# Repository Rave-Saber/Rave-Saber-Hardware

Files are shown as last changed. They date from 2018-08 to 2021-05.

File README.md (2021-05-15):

# RaveSaber - AVR Hardware

This repository contains the circuit diagram, PCB schematics, prototype board
layout, parts list, & setup guide for the RaveSaber electronics.

There is no blade or hilt at the moment, but you can swing the LEDs
around using the PCB or prototype board & a piece of wood.

## Electronics Design

The Rave Saber board includes voltage regulation, utility headers, input
buttons, and an Atmel ATmega168a microchip.

### Connectors

The various RaveSaber connectors

`J1` is where power enters the board from the battery. We use JST connectors
for our battery wiring. The battery power is fed through the power sub-circuit
to get a regulated voltage of 5V.

`J2` is where the Dotstar strips connect to the board. The data & clock signals
come from the microchip while the power connections come from the power
circuit.

`J3` & `J4` are optional connectors that ease programming & development. `J3`
is a FTDI Serial connection that can be used to preview/sample different colors
with our [color testing firmware][color-test]. `J4` is an ISP connector that
allows you to re-program the microchip without having to pull it out of it's
socket.

### Power

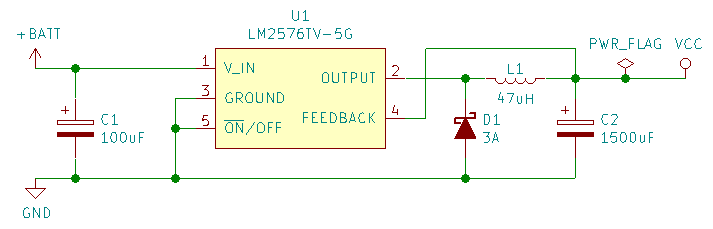
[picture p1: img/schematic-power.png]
The RaveSaber voltage regulation circuit


The power circuit uses a LM2576TV-5G switching voltage regulator to step down
the battery voltage to 5V. It can pump out a maximum of 3 Amps, which is used
to power the microcontroller & the LEDs.

The circuit design is derived from the voltage regulator's datasheet. `C1` &
`C2` should be low-ESR capacitors rated for at least 16V(with a minimum ESR of
50 milliOhms for `C2`). `C2` can be anywhere from 1000 to 2000 uF. `L1` must be
an inductor rated for at least 3 amps, going slightly over that is encouraged.
`D1` should be rated for 20V.

### Microcontroller

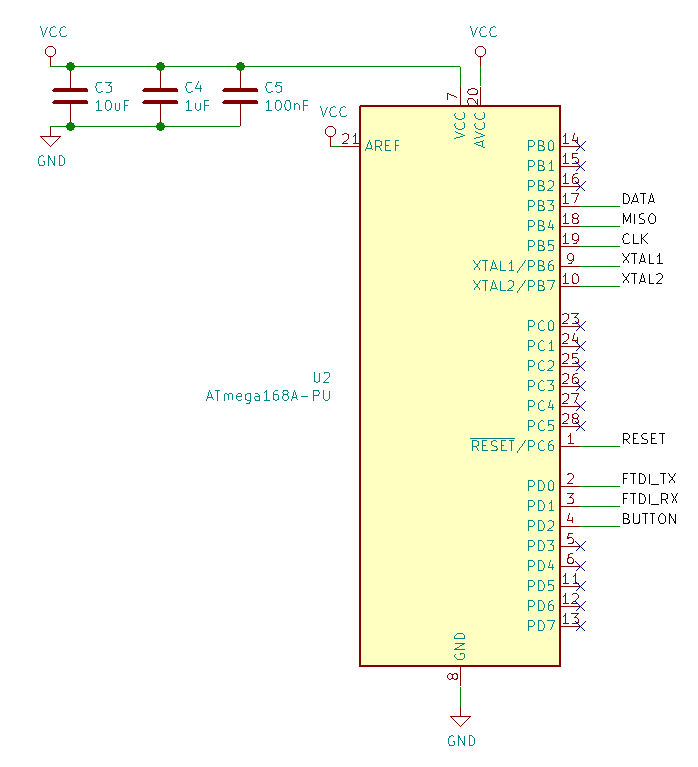
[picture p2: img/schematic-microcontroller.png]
The RaveSaber microcontroller connections


The microcontroller circuit is mostly just connections to the other circuits.

Bypass capacitors are used on the connection to the power circuit. `C3` & `C4`
are optional but `C5`, the 100nF capacitor, should always be included. The
analog reference & power pins are connected to the power supply even though
they are not used - this is recommended in the ATmega datasheet.

### Crystal Oscillator

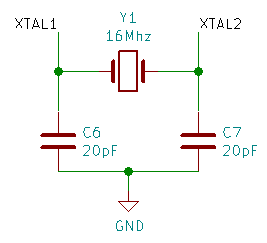
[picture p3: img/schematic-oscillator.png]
The RaveSaber oscillator circuit


The oscillator circuit is pretty fluid. You can use a different frequency
crystal(with a maximum of 20Mhz), or leave out the entire circuit and use the
ATmega's 8Mhz internal oscillator instead. If you do modify the circuit, make
sure your microcontroller's fuses are correctly programmed for your desired
clock source and change the definition of the `F_CPU` macro in the firmware's
`Makefile` to your new frequency.

### Button

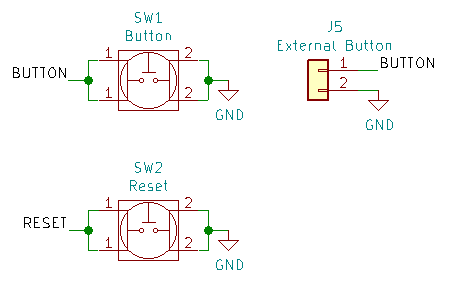
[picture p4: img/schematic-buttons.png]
The RaveSaber button circuits


The main button is `SW1`. It is used to ignite/extinguish the saber & cycle
through the programmed patterns. We've included both a tactile switch for
development and an external connection so you can put your board in a hilt.

The reset button, `SW2`, is optional but ocassionally useful for testing &
development.

## Required Materials

### Equipment

You'll want to have the following equipment/supplies:

* 22AWG Solid Hookup Wire
* AVR Programmer(like the [USBtinyISP][usbtinyisp])
* Wire Strippers
* Flush Cutters
* Soldering Iron & Solder
* PCB Holder(optional)
* Anti-static Bracelet or ESD-safe Tweezers(optional)

If you're only testing this out on a breadboard you can get away with just:

* Breadboard
* Wire & Strippers
* AVR Programmer
* 5V Power Supply

### Components

For the breadboard, you just need a Dotstar strip, an ATmega168a
microcontroller & a tactile button.

For the prototyping board, you will need the following:

| Part | Description | Link |
|---|---|---|
| | 22x27 through-hole prototyping board | [Amazon][protoboard] |
| BAT | 7.4v Li-Ion battery | [TCSS][battery] |
| LED | DotStar Strip, 144/m | [Mouser][led-strip] |
| J1 | 2-pin JST connector | [TCSS][jst-power-connector] |
| J2 | 4-pin, 2.54mm pitch male header | [Amazon][headers] |
| J3 | 6-pin, 2.54mm pitch male header | [Amazon][headers] |
| J4 | 2x3-pin, 2.54mm pitch male header | [Amazon][headers] |
| C1 | 100uF low-ESR electrolytic capacitor | [Mouser][100-cap] |
| C2 | 1000-2000uF low-ESR electrolytic capacitor | [Mouser][1200-cap] |
| C3 | 10uF capacitor | [Amazon(assorted)][elec-cap-kit] |
| C4 | 1uF capacitor | [Amazon(assorted)][elec-cap-kit] |
| C5 | 100nF capacitor | [Amazon(assorted)][cer-cap-kit] |
| C6, C7 | 20pF capacitor | [Mouser][20-cap] |
| D1 | 3A, 20V Schottky Diode | [Mouser][diode] |
| L1 | 47uH, 3A Fixed Inductor | [Mouser][inductor] |
| Y1 | 16Mhz Crystal | [Mouser][crystal] |
| SW1, SW2 | 6mm SPST OFF-(ON) tactile switch | [Mouser][switch] |
| U1 | LM2576TV-5G - 5V, 3A switching voltage regulator | [Mouser][vreg] |
| U2 | 28-pin DIP IC socket | [Amazon][dip-socket] |
| U2 | Atmel ATmega168A-PU - AVR microcontroller | [Mouser][atmega] |

[protoboard]: https://amzn.to/2L2IWVJ
[battery]: http://www.thecustomsabershop.com/74v-Li-ion-2600mAh-18650-Battery-Pack-P699.aspx
[led-strip]: https://www.mouser.com/ProductDetail/485-2242
[jst-power-connector]: https://www.thecustomsabershop.com/JST-Female-connector-24AWG-RedBlack-P964.aspx
[headers]: https://amzn.to/2Mx6HtK
[100-cap]: https://www.mouser.com/ProductDetail/710-870135675003
[1200-cap]: https://www.mouser.com/ProductDetail/667-EEU-FC1A122S
[elec-cap-kit]: https://amzn.to/2wb0Ekk
[cer-cap-kit]: https://amzn.to/2PiyX1K
[20-cap]: https://www.mouser.com/ProductDetail/594-S200K25SL0N63L6R
[diode]: https://www.mouser.com/ProductDetail/863-1N5820G
[inductor]: https://www.mouser.com/ProductDetail/673-PE-53112NL
[crystal]: https://www.mouser.com/ProductDetail/520-HCA1600-20X
[switch]: https://www.mouser.com/ProductDetail/506-FSM4JH
[vreg]: https://www.mouser.com/ProductDetail/863-LM2576TV-5G
[dip-socket]: https://amzn.to/2Mo4dOU
[atmega]: https://www.mouser.com/ProductDetail/556-ATMEGA168A-PU

For the circuit board, you will need SMD components instead:

| Part | Description | Link
|---|---|---|
| | RaveSaber v3.0.0 PCB | [OSHPark][pcb-3.0.0]
| BAT | 7.4v Li-Ion battery | [TCSS][battery] |
| LED | DotStar Strip, 144/m | [Mouser][led-strip] |
| J1 | 2-pin JST connector | [TCSS][jst-power-connector]
| J2 | 4-pin, 2.54mm pitch male header | [Mouser][pcb-4-pin]
| J3 | 6-pin, 2.54mm pitch male header | [Mouser][pcb-6-pin]
| J4 | 2x3-pin, 2.54mm pitch male header | [Mouser][pcb-2-3-pin]
| J5 | 2-pin JST connector | [TCSS][jst-switch-connector]
| C1 | 100uF low-ESR electrolytic capacitor | [Mouser][pcb-100-cap] |
| C2 | 1500uF low-ESR electrolytic capacitor | [Mouser][pcb-1500-cap] |
| C3 | 10uF capacitor | [Mouser][pcb-10-cap] |
| C4 | 1uF capacitor | [Mouser][pcb-1-cap] |
| C5 | 100nF capacitor | [Mouser][pcb-100n-cap] |
| C6, C7 | 20pF capacitor | [Mouser][pcb-20-cap] |
| D1 | 3A, 20V Schottky Diode | [Mouser][pcb-diode] |
| L1 | 47uH, 3A Fixed Inductor | [Mouser][pcb-inductor] |
| Y1 | 20Mhz Crystal | [Mouser][pcb-crystal] |
| SW1, SW2 | 4.5mm SPST OFF-(ON) tactile switch | [Mouser][pcb-switch] |
| U1 | LM2576TV-5G - 5V, 3A switching voltage regulator | [Mouser][vreg] |
| U2 | 28-pin DIP IC Socket | [Mouser][pcb-dip-socket] |
| U2 | Atmel ATmega168A-PU - AVR microcontroller | [Mouser][atmega] |

NOTE: The 4- & 6-pin headers link to a 20-pin header. We simply break this into
the sizes necessary with some pliers.

NOTE: The DIP socket for `U2` is machine-holed. You may prefer a leaf-spring
socket instead.

[pcb-3.0.0]: https://oshpark.com/shared_projects/t8VlH9g8
[pcb-4-pin]: https://www.mouser.com/ProductDetail/Samtec/TSM-120-01-S-SV-P
[pcb-6-pin]: https://www.mouser.com/ProductDetail/Samtec/TSM-120-01-S-SV-P
[pcb-2-3-pin]: https://www.mouser.com/ProductDetail/855-M20-8750342
[jst-switch-connector]: https://www.thecustomsabershop.com/JST-Female-connector-24AWG-BlueWhite-P958.aspx
[pcb-100-cap]: https://www.mouser.com/ProductDetail/661-EMZJ350A101MHA0G
[pcb-1500-cap]: https://www.mouser.com/ProductDetail/598-AFK158M16H32T-F
[pcb-10-cap]: https://www.mouser.com/ProductDetail/810-C1608X5R1E106M
[pcb-1-cap]: https://www.mouser.com/ProductDetail/80-C0603X105J4R
[pcb-100n-cap]: https://www.mouser.com/ProductDetail/581-0603X7R104JT1AT
[pcb-20-cap]: https://www.mouser.com/ProductDetail/603-CC603GRNPO9BN200
[pcb-diode]: https://www.mouser.com/ProductDetail/621-B320A-F
[pcb-inductor]: https://www.mouser.com/ProductDetail/710-744373965470
[pcb-crystal]: https://www.mouser.com/ProductDetail/559-FOXSDLF200-20
[pcb-switch]: https://www.mouser.com/ProductDetail/612-TL3305AF260QG
[pcb-dip-socket]: https://www.mouser.com/ProductDetail/575-1104732841105000

## Setup

### Breadboard

A breadboard can be used for simple testing of colors/patterns as well as
flashing the microchip with new firmware. You could use a smaller breadboard
for the saber instead of a prototyping board, but it's not nearly as durable.
Be wary of drawing too much current through your breadboard - you might melt
it! Initial attempts used batteries and voltage regulation with the breadboard,
but these instructions will assume you are running everything off a 5V bench
power supply.

1. Place the ATmega168a chip in the center of the breadboard.
1. Connect the switch to ground and pin 4(PD2/INT0) of the microchip.
1. Connect pin 19(SCK) to the Dotstar strip's clock pin & pin 17(MOSI) to the
   strip's data pin.
1. Connect your power supply's 5V & ground leads to the microchip & Dotstar
   strip.

You should now be able to connect the GND, SCK, MOSI, MISO, & RESET pins of
your programmer and flash your chip with the [RaveSaber Firmware][firmware].
Leave the VCC pin on your programmer unconnected since power is coming from
your bench supply.

### Prototyping Board

A prototyping board is the recommended way to setup v2.0.0 of the RaveSaber
hardware.

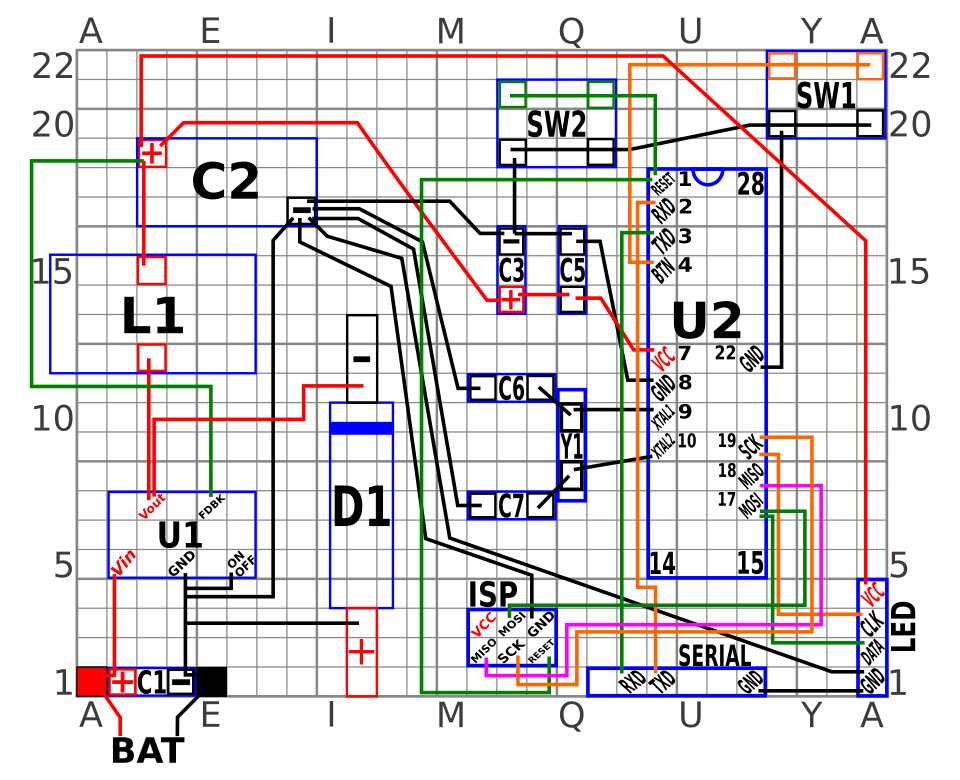
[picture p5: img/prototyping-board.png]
The Prototyping Board Layout of the RaveSaber v2.0.0


The prototyping board is assembled by placing components and bridging pads with
component leads, solder bridges, & wire. We've ommited `C4`, the 1uF decoupling
capacitor but feel free to add it in.

First we place the components and make what connections we can with the
component leads:

1. Start by placing the capacitors on the board and bending the leads so they
   stay on the board when you flip it over. You can also tack them into place
   with a small amount of solder.
1. Place the switches and voltage regulator. These should fit tight enough that
   they don't fall out when you flip the board over. If they do, tack them into
   place with some solder on the pins.
1. Place the DIP socket for `U2` and tack it into place by soldering some of
   the unused pins.
1. Connect `C1` and `U1` by bending the leads of `C1` and soldering them together.
1. Bridge `GND` & `ON/OFF` of `U1` together. This keeps the regulator always
   running.
1. Place and solder `L1`. Bend & solder the positive lead of `C2` to connect
   the two.
1. Since the leads of `D1` are too thick for the board's holes, bend them down
   the board and solder each one over multiple pads.
1. Connect and solder the negative leads of `C2`, `C3`, `C5`, & `SW2`. Do the
   same with the positive leads of `C3` & `C5`.
1. Use spare lead cuttings to bridge all the ground pins of `SW1` & `SW2`
   together. Bridge the top pins of each switch together as well, keeping the
   tops of `SW1` & `SW2` unconnected.
1. Place & solder `Y1`. Use the right leads of `C6` & `C7` to connect & solder
   them to the crystal and then to the proper DIP-socket pins.
1. Place and solder the `J2`, `J3`, & `J4` headers. Use just enough solder to
   get them to hold into place - it'll make their wire connections easier to
   solder.
1. Bridge the ground pins of the serial & LED headers together. Leave space for
   the ground wire between `C2` and the LED header.

Everything should now be on the board & the remaining connections can be made
with your 22-gauge wire. We did this in the following order:

1. `U1` to `L1`, `D1`, & `C2`.
1. `C3` positive lead to `C2`.
1. `C5` to VCC & GND of `U2`.
1. `U2` second GND(pin 22) to `SW1`.
1. `RESET` from `U2` to `SW2`.
1. `BTN` from `U2` to `SW1`.
1. `TXD` from `U2` to `RXD` of the serial header, followed by `RXD` to `TXD`.
1. `RESET` from `U2` to the ISP header.
1. `C2` to VCC & GND of the LED header.
1. `GND` from `C2` to `C6`, `C7`, & the ISP header.
1. `MOSI` & `SCK` from `U2` to the LED header.
1. `MOSI`, `MISO`, `SCK` from `U2` to the LED header.
1. Connect two wires to `C1` and terminate them with the JST connector.

Everything should be connected, your circuit should resemble the schematics, &
your prototyping board should resemble the above layout.

Place the ATmega168a into the DIP socket at `U2` & connect your Programmer's
ISP cable and the battery. Flash the [RaveSaber Firmware][firmware] &
disconnect the programmer & battery.

### PCB Assembly

You should be decent at soldering SMD components before attempting this.

We recommend soldering `C3` through `C7` first, followed by `U2`, `SW1`, `Y1`,
`SW2`, `J2` through `J4`, `D1`, `C1`, `L1`, `C2`, & finally `U2`. Use female
JST cables for `J1` & `J5`. Scrub with isopropyl alcohol to clean off any flux.

You can now insert & flash the microchip, plug in the battery, connect the
lights, and long-press `SW1` to extend the blade.

### Saber Blade / Hilt

The saber blade & hilt construction is very simple - we haven't put together a
blade or hilt yet so we just attach our LEDs & protoboard to a piece of wood.
We used a long 1x2 that we cut down after assembly. It's heavy, but you can
actually swing it around.

1. Lay your DotStar strip at the end of your board & secure it with 4-5
   zipties. Start at the far end, keeping the strip flat as you work towards
   the center of your wood.
1. Place the prototyping board below the strip, secure it with zipties at both
   ends and one in the center.
1. Flip the board over and place your battery near the board & strip, secure it
   with 3 zipties.
1. Connect the LED strip to the 4-pin header on the board and connect your
   battery to the board's JST connector.

You should now be able to long-press the button to illumunate the blade then
short-press to switch patterns or long-press again to power down the blade.

## TODO

* Auto-generate BOM(using [KiBoM](https://github.com/SchrodingersGat/KiBoM)?)
    * Make sure to add DIP socket, LED strips, etc. to BoM
* Blade construction guide, using TCSS blade parts
* PVC Hilt construction guide
    * Eventually use MHS hilts as well, but that's not open hardware
    * See how much it'd cost to get someone to design an open/free metal hilt
      that machinists could reproduce.
    * Chassis disk design, for use w/ acrylic laser cutting service or online
      machine shop.
* Contact Saber design
    * For doing moves [like this](https://youtu.be/Wgl2wym96k0)
    * Needs to be well balanced - some kind of chassis weighting?
    * Research best balance point for contact sabering
* Recharge port? Recharging blade stub?

### Future Milestones

Rough drafts of future plans

* v3.1.0 - 90deg ISP pins? Source single component for all 1-row pins & have
  assembler break apart. blade build + guide
* v4.0.0 - pcb & chassis that fits in MHS hilts

## References

### Hilts

* [Jay-gon's PVC Hilt Tutorial](http://forums.thecustomsabershop.com/showthread.php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)

### Blades

* [Neopixel Blade Assembly - FX-Sabers](https://www.fx-sabers.com/forum/index.php?PHPSESSID=06jl1sddsstpq4hvnu0c9fat74&topic=51357.0)
* [LED Blade Assembly](https://www.youtube.com/watch?v=Qbl4K-v4G_s)

## License

CERN OHL v1.2

[color-test]: https://github.com/Rave-Saber/AVR-APA102-Color-Tester
[usbtinyisp]: https://learn.adafruit.com/usbtinyisp/overview
[mouser]: https://mouser.com
[firmware]: https://github.com/Rave-Saber/Rave-Saber-Firmware

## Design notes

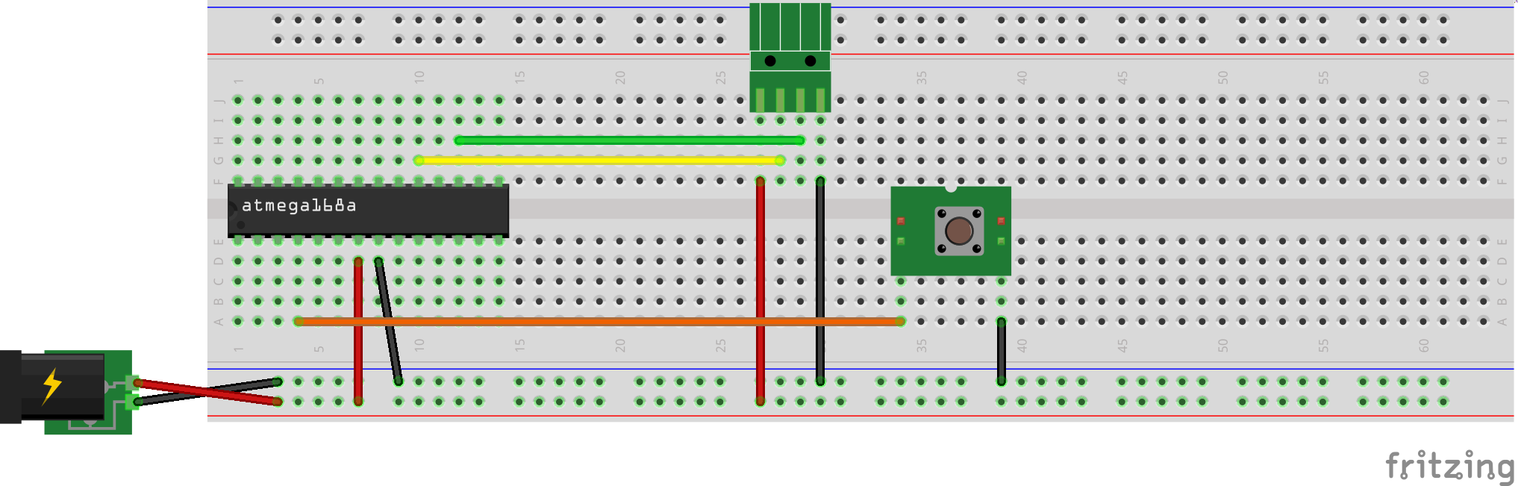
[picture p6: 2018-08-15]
img/breadboard.png

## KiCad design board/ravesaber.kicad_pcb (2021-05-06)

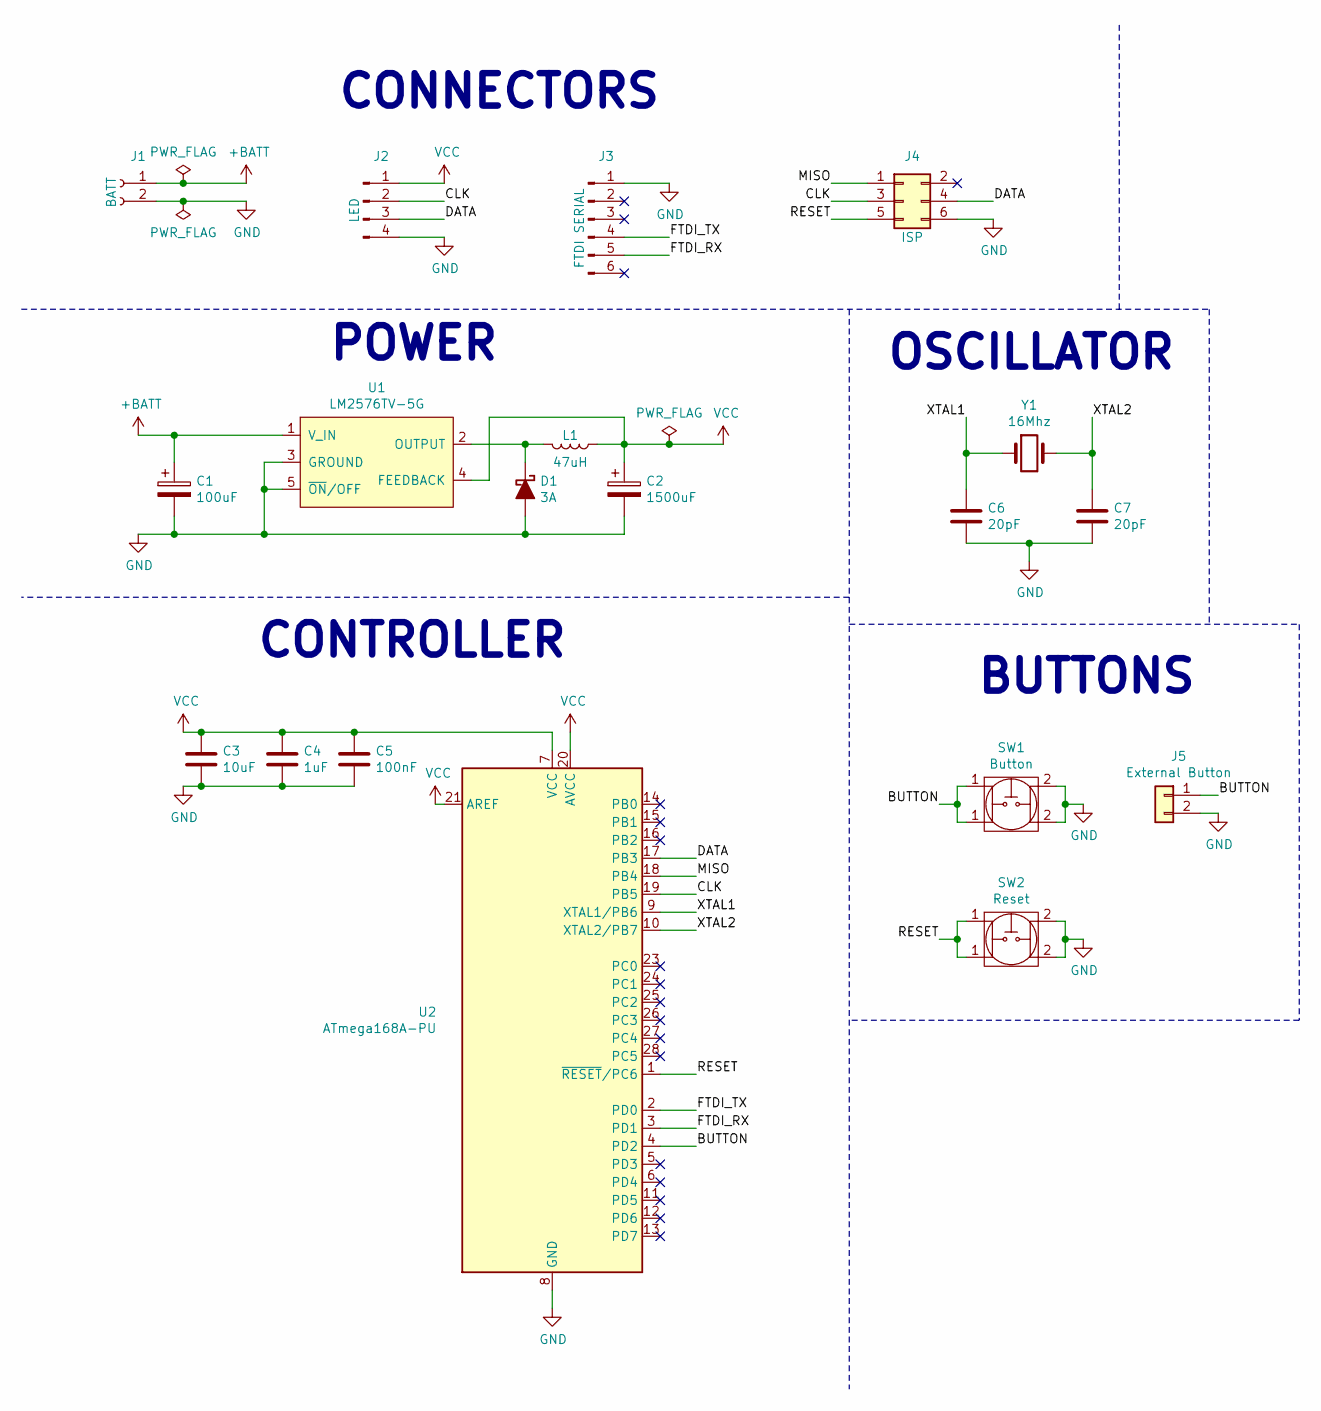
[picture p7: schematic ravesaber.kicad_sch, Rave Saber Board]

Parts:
C1: 100uF; CP_Elec_8x10; Mouser # 661-EMZJ350A101MHA0G
C2: 1500uF; CP_Elec_16x17.5; Mouser # 598-AFK158M16H32T-F
C3: 10uF; C_0603_1608Metric_Pad1.05x0.95mm_HandSolder; Mouser # 810-C1608X5R1E106M
C4: 1uF; C_0603_1608Metric_Pad1.05x0.95mm_HandSolder; Mouser # 80-C0603X105J4R
C5: 100nF; C_0603_1608Metric_Pad1.05x0.95mm_HandSolder; Mouser # 581-0603X7R104JT1AT
C6, C7: 20pF; C_0603_1608Metric_Pad1.05x0.95mm_HandSolder; Mouser # 603-CC603GRNPO9BN200
D1: 3A; D_SMA_Handsoldering; Mouser # 621-B320A-F
J1: BATT; SolderWirePad_1x02_P3.81mm_Drill1.2mm
J2: LED; PinHeader_1x04_P2.54mm_Vertical_SMD_Pin1Left; Mouser # 437-3508010400106101
J3: FTDI SERIAL; PinHeader_1x06_P2.54mm_Vertical_SMD_Pin1Left; Mouser # 855-M20-8770642R
J4: ISP; PinHeader_2x03_P2.54mm_Vertical_SMD; Mouser # 855-M20-8750342
J5: External Button; SolderWirePad_1x02_P3.81mm_Drill1.2mm
L1: 47uH; Wuerth WE-LHMI SMD; Mouser # 710-744373965470
SW1: Button; SW_SPST_TL3305A; Mouser # 612-TL3305AF260QG
SW2: Reset; SW_SPST_TL3305A; Mouser # 612-TL3305AF260QG
U1: LM2576TV-5G; TO-220-5_P3.4x3.7mm_StaggerOdd_Lead3.8mm_Vertical; Mouser # 863-LM2576TV-5G
U2: ATmega168A-PU; DIP-28_W8.89mm_SMDSocket_LongPads; Mouser # 556-ATMEGA168A-PU
Y1: 16Mhz; Crystal_SMD_HC49-SD; Mouser # 559-FOXSD160-20-LF

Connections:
+BATT: C1.1, J1.1, U1.1 (V_IN)
/BUTTON: J5.1, SW1.1, U2.4 (PD2)
/CLK: J2.2, J4.3, U2.19 (PB5)
/DATA: J2.3, J4.4, U2.17 (PB3)
/FTDI_RX: J3.5, U2.3 (PD1)
/FTDI_TX: J3.4, U2.2 (PD0)
/MISO: J4.1, U2.18 (PB4)
/RESET: J4.5, SW2.1, U2.1 (~RESET~/PC6)
/XTAL1: C6.1, U2.9 (XTAL1/PB6), Y1.1
/XTAL2: C7.1, U2.10 (XTAL2/PB7), Y1.2
GND: C1.2, C2.2, C3.2, C4.2, C5.2, C6.2, C7.2, D1.2 (A), J1.2, J2.4, J3.1, J4.6, J5.2, SW1.2, SW2.2, U1.3 (GROUND), U1.5 (~ON~/OFF), U2.8 (GND), U2.22 (GND)
unnamed: D1.1 (K), L1.2, U1.2 (OUTPUT)
VCC: C2.1, C3.1, C4.1, C5.1, J2.1, L1.1, U1.4 (FEEDBACK), U2.7 (VCC), U2.20 (AVCC), U2.21 (AREF)

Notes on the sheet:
CONTROLLER
POWER
CONNECTORS
OSCILLATOR
BUTTONS

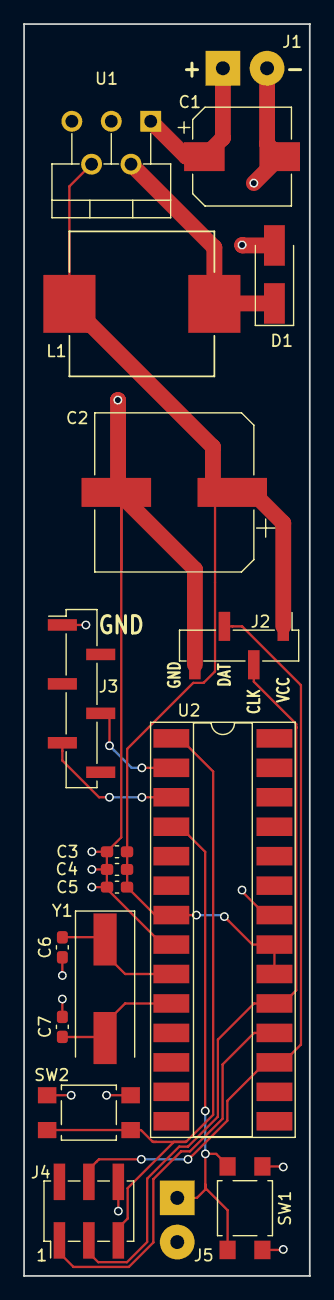
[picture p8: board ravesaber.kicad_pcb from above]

Board: 2 copper layers, 24.6 x 108.0 mm, 20 parts (1 on the bottom side), 13 nets.

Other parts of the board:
svg2mod: G***; AntiFA_Logo

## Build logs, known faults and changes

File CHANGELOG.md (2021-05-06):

# CHANGELOG

## master

* Fix machine-pin component for `J2` and component/footprint mismatch for `J3`.
  The previous `J2` component we linked to had pin diameters much too small to
  hook up to the DotStar strip. The previous `J3` component had the solder pad
  for pin 1 on the right side of the footprint instead of the left side.  To
  address this, we link to a 20-pin strip with proper pin widths & break them
  into the sizes & orientations necessary.
* Move Jumper & Switch silkscreen labels to outside their footprints.
* Switch the 0603 Capacitor footprints to a slightly more elongated version.
* Shift the footprint of SW2 up so that it's courtyard does not
  intersect with J4's.
* Ensure L1 silkscreen does not intersect with solder pads.
* Fix footprint size of C2 by creating a new custom footprint.

## v3.0.0

This version upgrades the prototyping board & through-hole components to a
printable PCB design & SMD components. We've also bumped the oscillator crystal
to 20Mhz to squeeze as much power out of the microcontroller as possible.

* Add KiCAD PCB schematic with SMD components.

## v2.0.0

This is actually a portable version that you can swing around. The electronics
are constructed on a prototyping board so they are much more secure than the
breadboard, and a voltage regulator has been added so we can run off of
rechargable 7.4V Li-Ion batteries.

There is still no blade or hilt design though - swinging this around means
attaching the LED & electronics to a piece of wood.

* Document the electronics circuit design.
* Add an example layout for a prototyping board along with a list of required
  components and a build guide.
* Add power sub-circuit that uses a switching voltage regulator so the LEDs &
  microcontroller can run off of batteries.
* Add 10, 1, & 0.1 uF decoupling capacitors to the microcontroller's power &
  ground lines.
* Add a 16Mhz oscillator sub-circuit. This is only used if the
  microcontroller's fuses are set to use an external full-swing crystal.
* Add a reset button & pads for an external button.
* Add headers for programming & serial cables.
* Add KiCAD project for schematic.

## v1.0.0

The simplest way to start - connecting everything on a breadboard! This design
uses a tactile switch, headers for connecting the DotStar cable, and Atmel
ATmega168a microchip, and a 5V bench power supply.

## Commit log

2018-07-03 Add Parts/Setup Info, Schematics, BOM, & Breadboard Drawing
    [Mouser_BOM.xls, fritzing_sketch.fzz]
2018-08-13 Use KiCAD to Create Schematic
    This adds a new KiCAD v5 project to the repository, containing a new
    board schematic with a custom symbol for the voltage regulator, as well
    a footprint for our eventual SMD inductor.
    The new schematic includes a voltage regulation circuit for running off
    of battery power, a reset button, a crystal oscillator circuit,
    decoupling capacitors on the chip's power pins & ISP/FTDI headers.
    [ravesaber.sch]
2018-08-13 Add Design & Prototyping Board Documentation
    Add some documentation about the current electronic circuit's design, as
    well as a prototyping board layout with a materials/equipment list &
    setup guide.
2018-08-13 Remove the Fritzing Files
    [fritzing_sketch.fzz]
2018-08-13 Fix Link to Button Schematics Image
2018-08-13 Fix RX/TX Connections in Prototyping Board Layout
2018-08-18 Add Links to Purchase Parts to README
    [Mouser_BOM.xls]
2018-08-20 Prepare for v2.0.0
    [ravesaber.sch]
2021-05-04 Add a KiCAD PCB Schematic With SMD Components
    Add a 1" PCB & migrate to SMD components. We've bumped C2 to 1500 uF &
    the crystal oscillator to 20Mhz. Blank through-holes have been added for
    battery & switch cables.
    This PCB has been printed by OSHPark & tested by us.
    [ravesaber.kicad_pcb, ravesaber.kicad_sch, ravesaber.sch]
2021-05-04 Update README With PCB Documentation
2021-05-04 Link to JST Cables Instead of Connectors
2021-05-06 Fix Footprint Size for C2, Fix Silkscreen for L1
    Create a new CP_Elec footprint using the datasheet for C2, swapping out
    the footprint in the PCB schematic.
    Fix the Silkscreen layer for the L1 footprint, ensuring it does not
    cross the pads.
    Shift the SW2 footprint up so that it's courtyard does not overlap the
    courtyard of J4.
    [ravesaber.kicad_pcb]
2021-05-06 Change 0603 Capacitors to New Footprint
    Switch the PCB footprints for the 0603 SMD Capacitors to the new
    1.08x0.95mm hand-soldering version from KiCad 5.99.
    [ravesaber.kicad_pcb]
2021-05-06 Refill All PCB Ground Plane Zones
    [ravesaber.kicad_pcb]
2021-05-06 Move Jumper & Switch Labels Outside of Their Footprints
    [ravesaber.kicad_pcb]
2021-05-06 Fix Component Links for J2 & J3; Add Note That U2 is Machine-Holed

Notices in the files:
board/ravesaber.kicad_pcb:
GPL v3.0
